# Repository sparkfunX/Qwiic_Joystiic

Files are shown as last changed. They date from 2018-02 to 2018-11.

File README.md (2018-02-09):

# Qwiic_Joystiic
Thumbstick Breakout for the Qwiic System
<br/><br/>
Factory Default I2C Slave Address: 0x20<br/>
<br/>
<h3 style="text-decoration: underline;">I2C Registers</h3><br/>

| Address | Contents |
| --- | --- |
| 0x00-0x01 | Horizontal Position (MSB First) |
| 0x02-0x03 | Vertical Position (MSB First) |
| 0x04 | Button Position |
| 0x06 | Current I2C Slave Address from EEPROM |
<br/>
<h3 style="text-decoration: underline;">I2C Commands</h3><br/>

| Address | Command |
| --- | --- |
| 0x05 | Set I2C Slave Address |

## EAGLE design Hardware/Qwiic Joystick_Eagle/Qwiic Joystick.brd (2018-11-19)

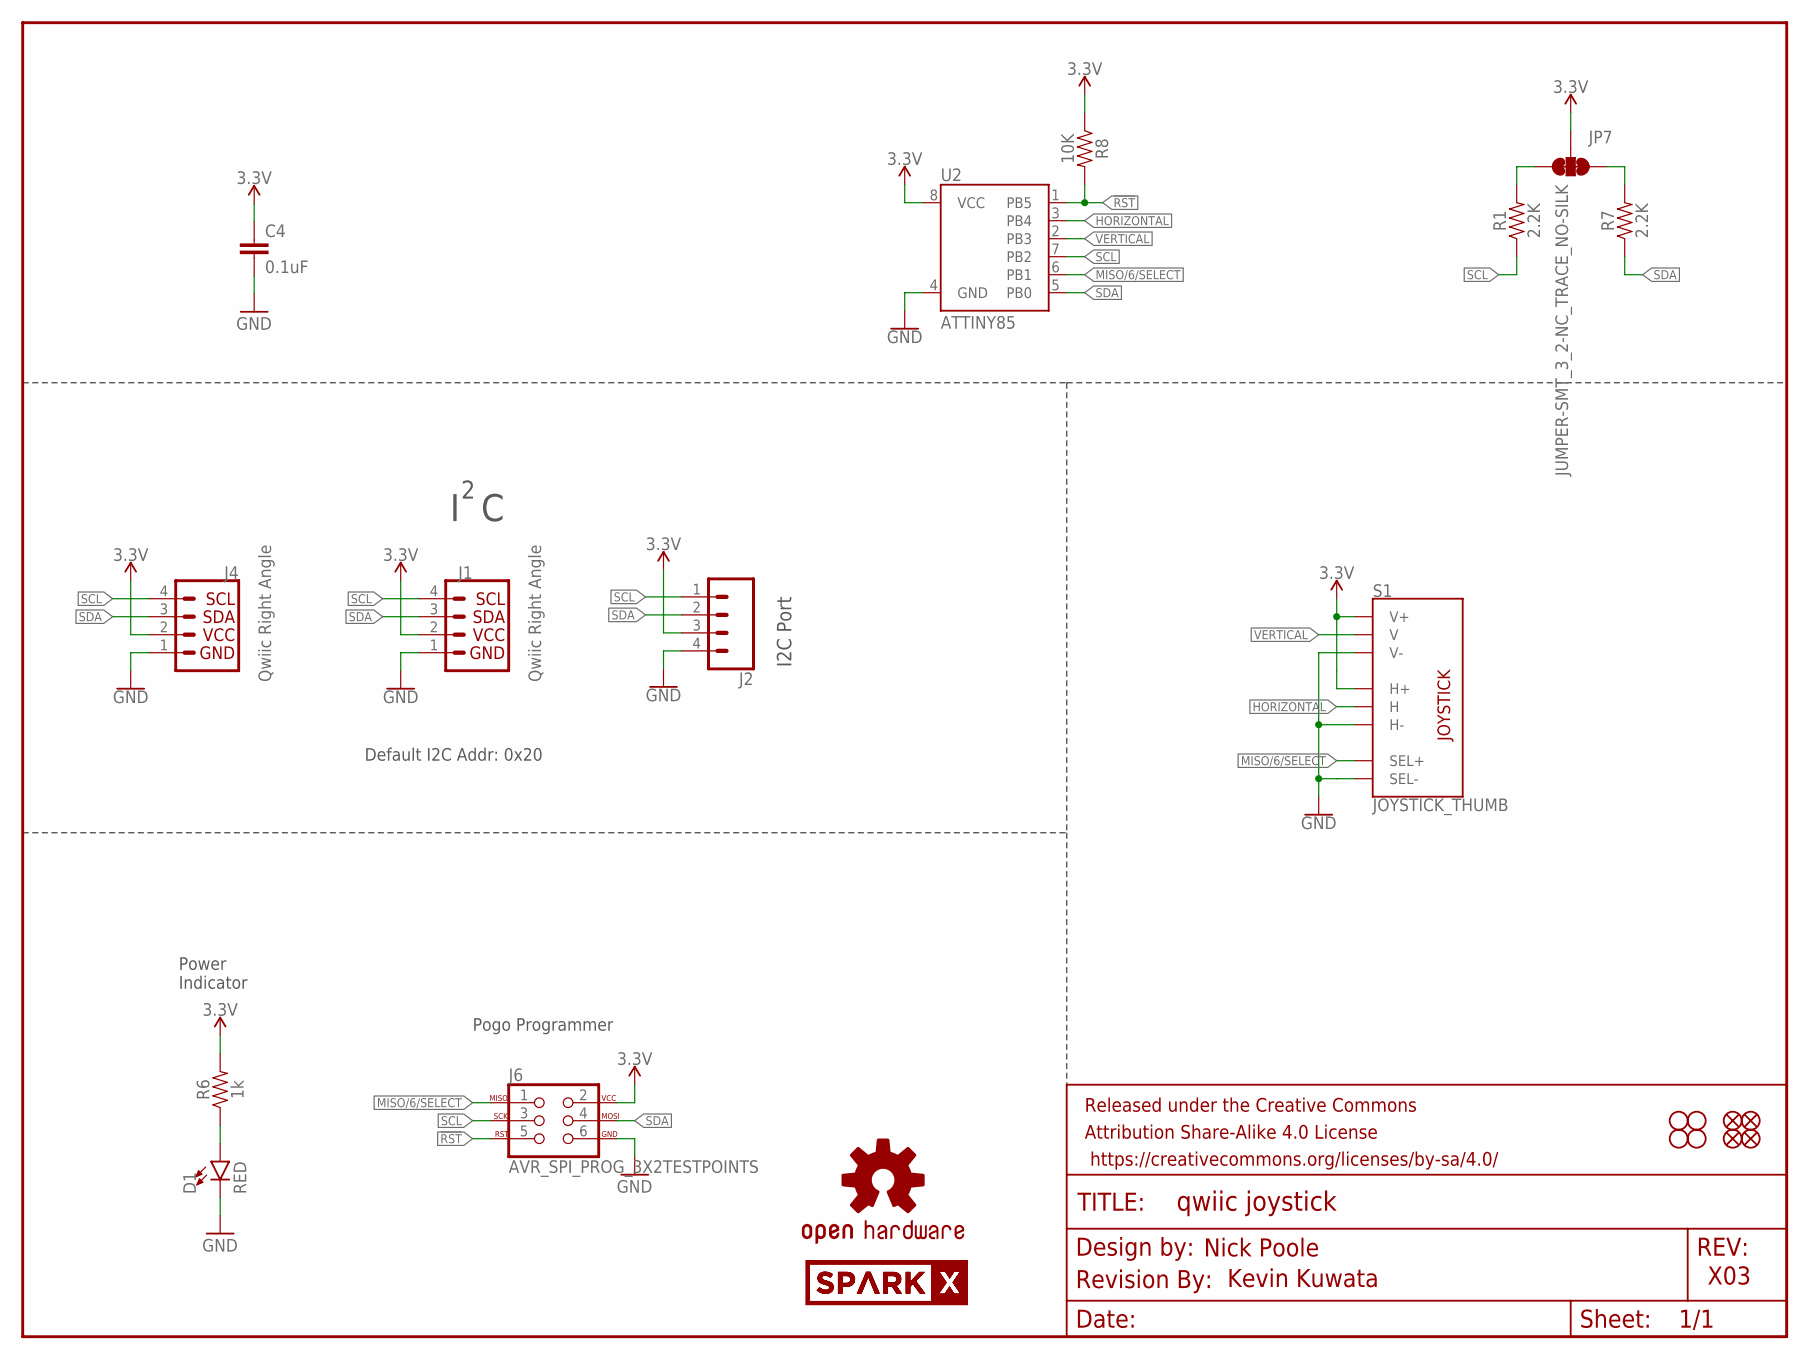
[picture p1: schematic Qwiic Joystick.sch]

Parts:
C4: 0.1uF; 0603
D1: RED; LED-0603
FRAME1: FRAME-LETTER; CREATIVE_COMMONS
H1, H2, H3, H4: STAND-OFF
J1, J4: Qwiic Right Angle; 1X04_1MM_RA
J2: CONN_041X04_NO_SILK; 1X04_NO_SILK
J6: AVR_SPI_PROG_3X2TESTPOINTS; 2X3_TEST_POINTS
JP1, JP2, JP3, JP6: FIDUCIALUFIDUCIAL; MICRO-FIDUCIAL
JP7: JUMPER-SMT_3_2-NC_TRACE_NO-SILK; SMT-JUMPER_3_2-NC_TRACE_NO-SILK
LOGO1: OSHW-LOGOMINI; OSHW-LOGO-MINI
LOGO2: REVISION
R1, R7: 2.2K; 0603
R6: 1k; 0603
R8: 10K; 0603
S1: JOYSTICK_THUMB; JOYSTICK
U2: ATTINY85
U$1, U$2: SPARKX-LOGO3; SPARKX-SMALL

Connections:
3.3V: C4.1, J1.2, J2.3, J4.2, J6.2, JP7.2, R6.2, R8.1, S1.H1 (H+), S1.V1 (V+), U2.8 (VCC)
!RST: J6.5, R8.2, U2.1 (PB5)
GND: C4.2, D1.C, J1.1, J2.4, J4.1, J6.6, S1.B2A (SEL-), S1.H3 (H-), S1.V3 (V-), U2.4 (GND)
HORIZONTAL: S1.H2 (H), U2.3 (PB4)
MISO/6/SELECT: J6.1, S1.B1A (SEL+), U2.6 (PB1)
unnamed: D1.A, R6.1
unnamed: JP7.1, R7.2
unnamed: JP7.3, R1.2
SCL: J1.4, J2.1, J4.4, J6.3, R1.1, U2.7 (PB2)
SDA: J1.3, J2.2, J4.3, J6.4, R7.1, U2.5 (PB0)
VERTICAL: S1.V2 (V), U2.2 (PB3)

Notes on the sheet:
Nick Poole
X03
I C
Power Indicator
Kevin Kuwata
I2C Port
Pogo Programmer
Default I2C Addr: 0x20

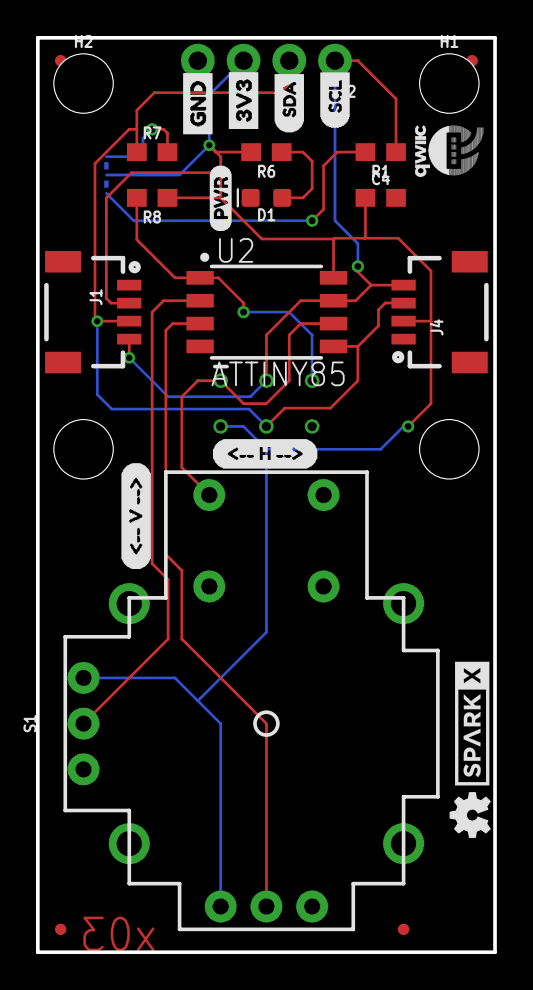
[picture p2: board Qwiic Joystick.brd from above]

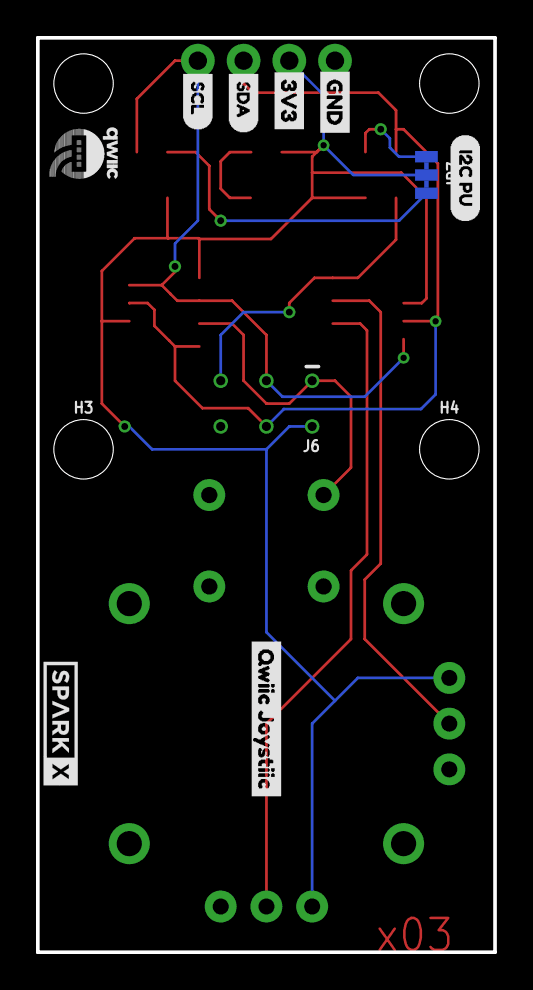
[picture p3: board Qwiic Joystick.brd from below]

Board: 2 copper layers, 25.4 x 50.8 mm, 41 parts (12 on the bottom side), 11 nets.

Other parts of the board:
U$3: QWIIC_JOYSTIIC6
U$4: I2C_PU0
U$5: SDA0
U$6, U$8: GND4
U$7: ###_V_###0
U$9: SCL1
U$10, U$22: QWIIC-LOGO-SMALL
U$11: SCL3
U$12: SDA2
U$14: PWR-()-03
U$15: ###_H_###1
U$16, U$17: 3V35

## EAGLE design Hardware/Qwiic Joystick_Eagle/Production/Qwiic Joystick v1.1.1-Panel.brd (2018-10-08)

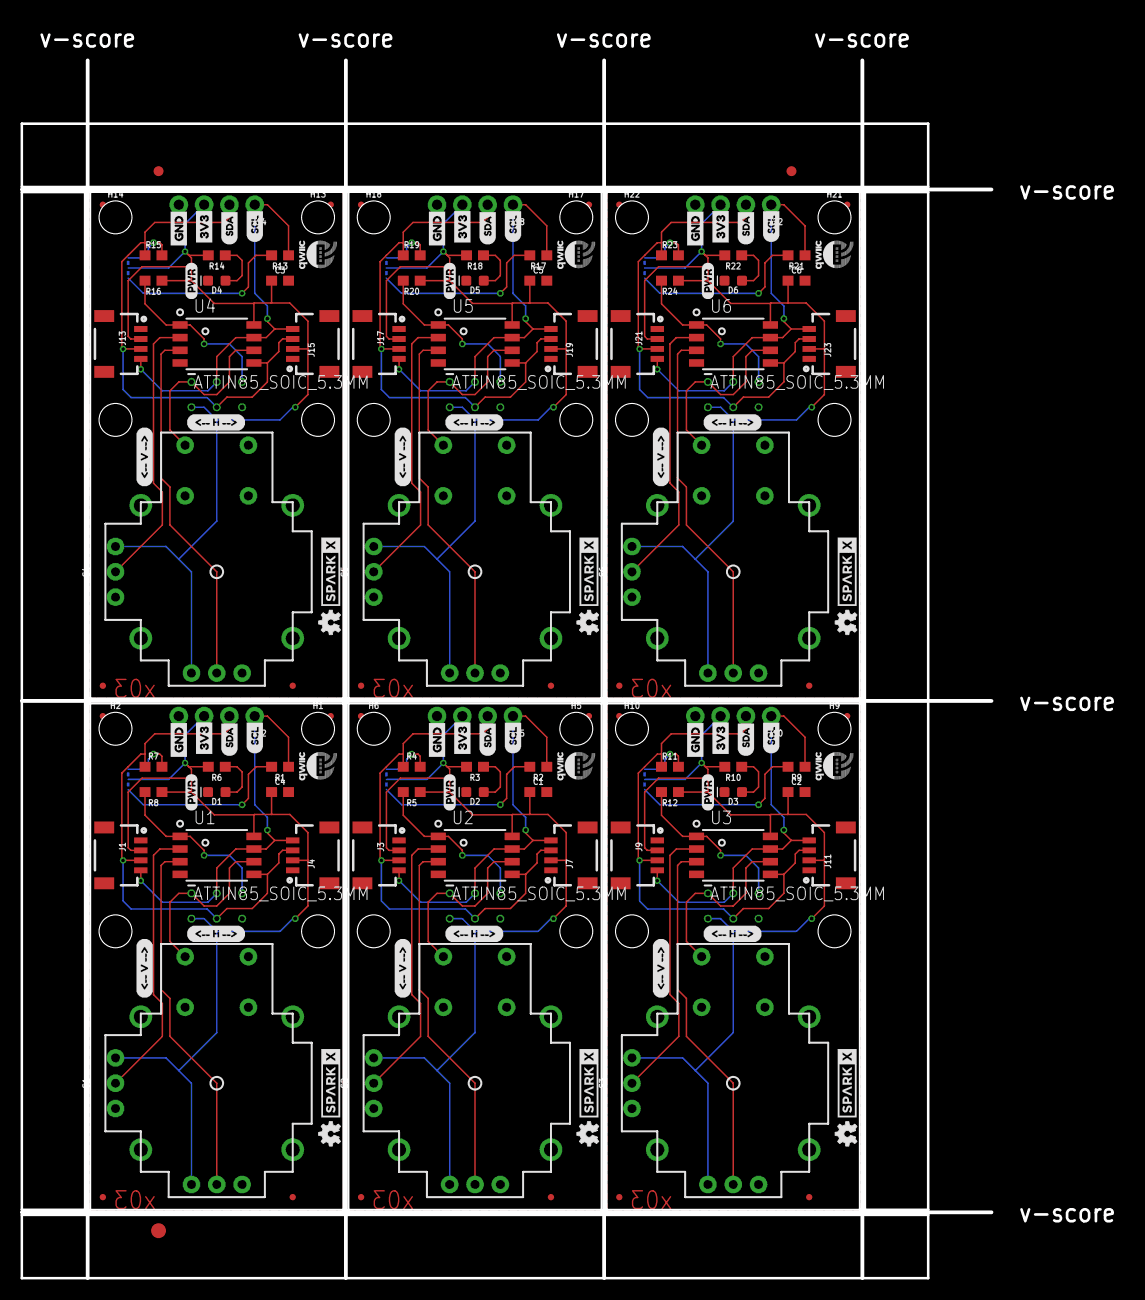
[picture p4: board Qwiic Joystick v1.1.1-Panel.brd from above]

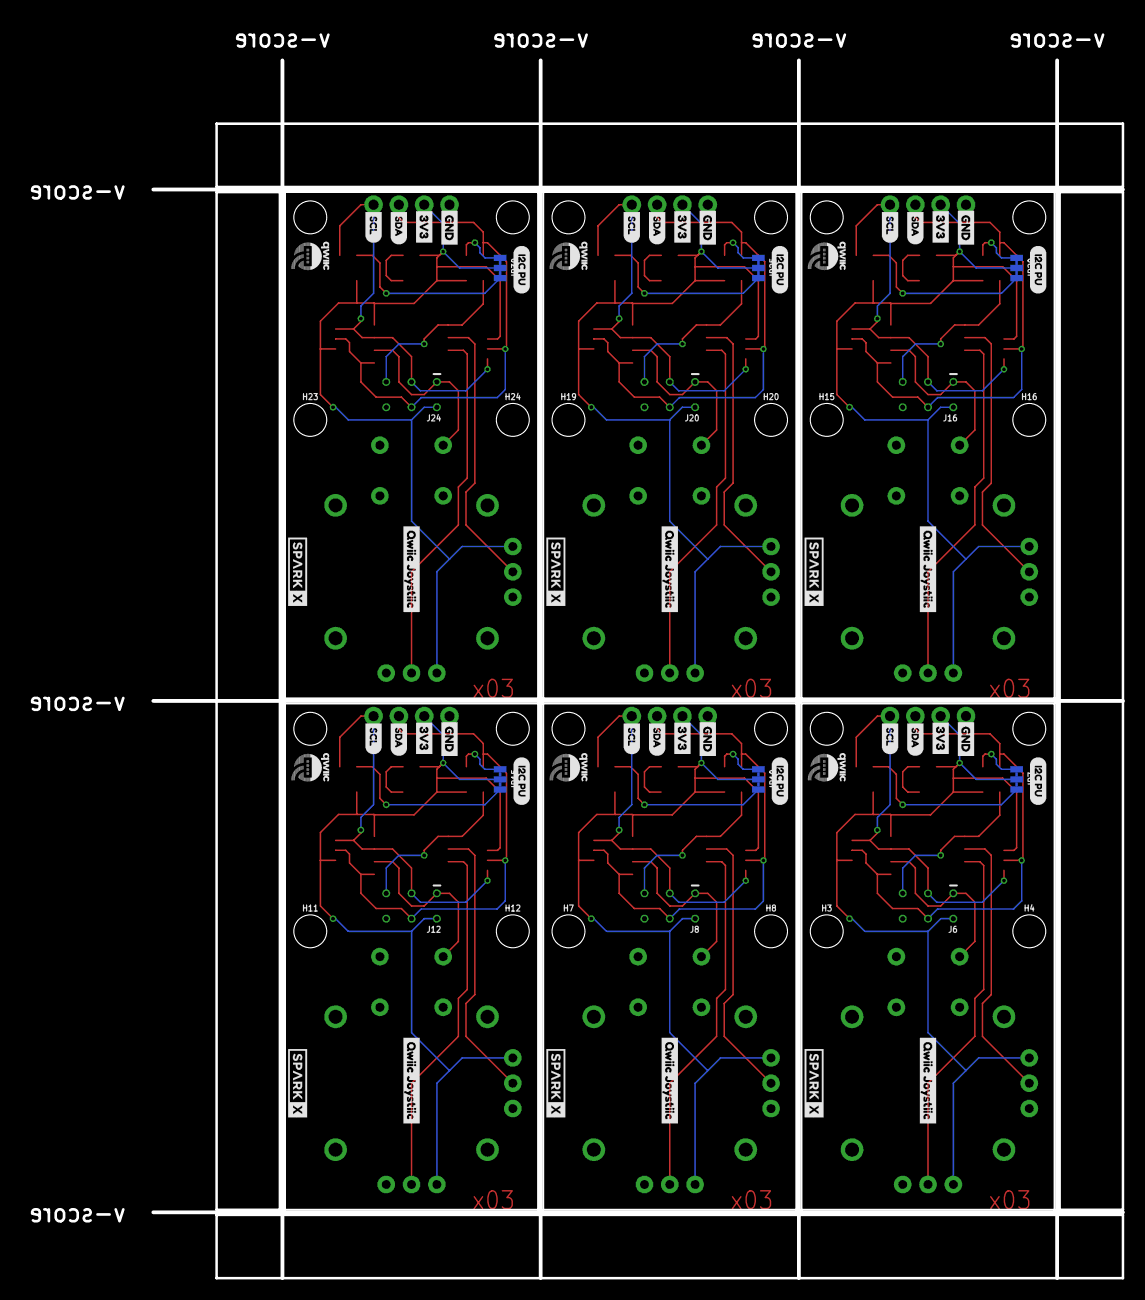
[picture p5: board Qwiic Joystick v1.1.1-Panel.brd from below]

Board: 2 copper layers, 97.3 x 122.2 mm, 243 parts (72 on the bottom side), 66 nets.

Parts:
C1, C2, C3, C4, C5, C6: 0.1uF; 0603
D1, D2, D3, D4, D5, D6: RED; LED-0603
E$1, E$2: FIDUCIAL-1X2
E$3: FIDUCIAL-1.5X3
FRAME1, FRAME2, FRAME3, FRAME4, FRAME5, FRAME6: FRAME-LETTER; CREATIVE_COMMONS
H1, H2, H3, H4, H5, H6, H7, H8, H9, H10, H11, H12, H13, H14, H15, H16, H17, H18, H19, H20, H21, H22, H23, H24: STAND-OFF
J1, J3, J4, J7, J9, J11, J13, J15, J17, J19, J21, J23: Qwiic Right Angle; 1X04_1MM_RA
J2, J5, J10, J14, J18, J22: 1X04_NO_SILK
J6, J8, J12, J16, J20, J24: AVR_SPI_PROG_3X2TESTPOINTS; 2X3_TEST_POINTS
JP1, JP2, JP3, JP4, JP5, JP6, JP8, JP9, JP11, JP12, JP13, JP14, JP16, JP17, JP18, JP19, JP21, JP22, JP23, JP24, JP26, JP27, JP28, JP29: FIDUCIALUFIDUCIAL; MICRO-FIDUCIAL
JP7, JP10, JP15, JP20, JP25, JP30: JUMPER-SMT_3_2-NC_TRACE_NO-SILK; SMT-JUMPER_3_2-NC_TRACE_NO-SILK
LOGO1, LOGO2, LOGO3, LOGO4, LOGO5, LOGO6: OSHW-LOGOMINI; OSHW-LOGO-MINI
R1, R2, R4, R7, R9, R11, R13, R15, R17, R19, R21, R23: 2.2K; 0603
R3, R6, R10, R14, R18, R22: 1k; 0603
R5, R8, R12, R16, R20, R24: 10K; 0603
S1, S2, S3, S4, S5, S6: JOYSTICK_THUMB; JOYSTICK
U1, U2, U3, U4, U5, U6: ATTIN85_SOIC_5.3MM; ATTINY85
U$1, U$2, U$13, U$18, U$35, U$36, U$52, U$53, U$69, U$70, U$86, U$87: SPARKX-LOGO3; SPARKX-SMALL
U$3, U$29, U$46, U$63, U$80, U$97: QWIIC_JOYSTIIC6
U$4, U$34, U$51, U$68, U$85, U$102: I2C_PU0
U$5, U$25, U$42, U$59, U$76, U$93: SDA0
U$6, U$8, U$30, U$31, U$47, U$48, U$64, U$65, U$81, U$82, U$98, U$99: GND4
U$7, U$21, U$39, U$56, U$73, U$90: ###_V_###0
U$9, U$26, U$43, U$60, U$77, U$94: SCL1
U$10, U$19, U$22, U$24, U$37, U$41, U$54, U$58, U$71, U$75, U$88, U$92: QWIIC-LOGO-SMALL
U$11, U$27, U$44, U$61, U$78, U$95: SCL3
U$12, U$28, U$45, U$62, U$79, U$96: SDA2
U$14, U$20, U$38, U$55, U$72, U$89: PWR-()-03
U$15, U$23, U$40, U$57, U$74, U$91: ###_H_###1
U$16, U$17, U$32, U$33, U$49, U$50, U$66, U$67, U$83, U$84, U$100, U$101: 3V35

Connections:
3.3V: C4.1, J1.2, J2.3, J4.2, J6.2, JP7.2, R6.2, R8.1, S1.H1, S1.V1, U1.8
3.3V1: C1.1, J3.2, J5.3, J7.2, J8.2, JP10.2, R3.2, R5.1, S2.H1, S2.V1, U2.8
3.3V2: C2.1, J9.2, J10.3, J11.2, J12.2, JP15.2, R10.2, R12.1, S3.H1, S3.V1, U3.8
3.3V3: C3.1, J13.2, J14.3, J15.2, J16.2, JP20.2, R14.2, R16.1, S4.H1, S4.V1, U4.8
3.3V4: C5.1, J17.2, J18.3, J19.2, J20.2, JP25.2, R18.2, R20.1, S5.H1, S5.V1, U5.8
3.3V5: C6.1, J21.2, J22.3, J23.2, J24.2, JP30.2, R22.2, R24.1, S6.H1, S6.V1, U6.8
!RST: J6.5, R8.2, U1.1
!RST1: J8.5, R5.2, U2.1
!RST2: J12.5, R12.2, U3.1
!RST3: J16.5, R16.2, U4.1
!RST4: J20.5, R20.2, U5.1
!RST5: J24.5, R24.2, U6.1
GND: C4.2, D1.C, J1.1, J2.4, J4.1, J6.6, S1.B2A, S1.H3, S1.V3, U1.4
GND1: C1.2, D2.C, J3.1, J5.4, J7.1, J8.6, S2.B2A, S2.H3, S2.V3, U2.4
GND2: C2.2, D3.C, J9.1, J10.4, J11.1, J12.6, S3.B2A, S3.H3, S3.V3, U3.4
GND3: C3.2, D4.C, J13.1, J14.4, J15.1, J16.6, S4.B2A, S4.H3, S4.V3, U4.4
GND4: C5.2, D5.C, J17.1, J18.4, J19.1, J20.6, S5.B2A, S5.H3, S5.V3, U5.4
GND5: C6.2, D6.C, J21.1, J22.4, J23.1, J24.6, S6.B2A, S6.H3, S6.V3, U6.4
HORIZONTAL: S1.H2, U1.3
HORIZONTAL1: S2.H2, U2.3
HORIZONTAL2: S3.H2, U3.3
HORIZONTAL3: S4.H2, U4.3
HORIZONTAL4: S5.H2, U5.3
HORIZONTAL5: S6.H2, U6.3
MISO/6/SELECT: J6.1, S1.B1A, U1.6
MISO/6/SELECT1: J8.1, S2.B1A, U2.6
MISO/6/SELECT2: J12.1, S3.B1A, U3.6
MISO/6/SELECT3: J16.1, S4.B1A, U4.6
MISO/6/SELECT4: J20.1, S5.B1A, U5.6
MISO/6/SELECT5: J24.1, S6.B1A, U6.6
unnamed: D1.A, R6.1
unnamed: JP7.1, R7.2
unnamed: JP7.3, R1.2
unnamed: D2.A, R3.1
unnamed: JP10.1, R4.2
unnamed: JP10.3, R2.2
unnamed: D3.A, R10.1
unnamed: JP15.1, R11.2
unnamed: JP15.3, R9.2
unnamed: D4.A, R14.1
unnamed: JP20.1, R15.2
unnamed: JP20.3, R13.2
unnamed: D5.A, R18.1
unnamed: JP25.1, R19.2
unnamed: JP25.3, R17.2
unnamed: D6.A, R22.1
unnamed: JP30.1, R23.2
unnamed: JP30.3, R21.2
SCL: J1.4, J2.1, J4.4, J6.3, R1.1, U1.7
SCL1: J3.4, J5.1, J7.4, J8.3, R2.1, U2.7
SCL2: J9.4, J10.1, J11.4, J12.3, R9.1, U3.7
SCL3: J13.4, J14.1, J15.4, J16.3, R13.1, U4.7
SCL4: J17.4, J18.1, J19.4, J20.3, R17.1, U5.7
SCL5: J21.4, J22.1, J23.4, J24.3, R21.1, U6.7
SDA: J1.3, J2.2, J4.3, J6.4, R7.1, U1.5
SDA1: J3.3, J5.2, J7.3, J8.4, R4.1, U2.5
SDA2: J9.3, J10.2, J11.3, J12.4, R11.1, U3.5
SDA3: J13.3, J14.2, J15.3, J16.4, R15.1, U4.5
SDA4: J17.3, J18.2, J19.3, J20.4, R19.1, U5.5
SDA5: J21.3, J22.2, J23.3, J24.4, R23.1, U6.5
VERTICAL: S1.V2, U1.2
VERTICAL1: S2.V2, U2.2
VERTICAL2: S3.V2, U3.2
VERTICAL3: S4.V2, U4.2
VERTICAL4: S5.V2, U5.2
VERTICAL5: S6.V2, U6.2

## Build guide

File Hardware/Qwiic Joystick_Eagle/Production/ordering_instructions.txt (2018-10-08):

panel size, 91x116mm
PCB thickness, 1.6mm
number of layers, 2
soldermask color, Black
silkscreen color, White
oz copper, 1oz
finish, HASL lead free
stencils, top
pcs per panel, 6

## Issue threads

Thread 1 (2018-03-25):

No Wire.endTransmission() after a Wire.requestFrom() please.

Koepel, 2018-03-25:
In the file "Example3-ReactionGame.ino" there is twice a Wire.endTransmission() after a Wire.requestFrom().
Explanation: [Common-mistakes#2](https://github.com/Koepel/How-to-use-the-Arduino-Wire-library/wiki/Common-mistakes#2)

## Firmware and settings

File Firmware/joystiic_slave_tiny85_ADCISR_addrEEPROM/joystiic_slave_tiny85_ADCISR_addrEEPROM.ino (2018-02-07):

#include <TinyWire.h> //https://github.com/lucullusTheOnly/TinyWire
#include <avr/sleep.h>
#include <EEPROM.h>

#define REG_MAP_SIZE         7
#define MAX_SENT_BYTES       3

#define ADC1_ADDRESS_MSB         0x00
#define ADC2_ADDRESS_MSB         0x02
#define BTN1_ADDRESS             0x04

byte registerMap[REG_MAP_SIZE];
byte registerMapTemp[REG_MAP_SIZE - 1];
byte receivedCommands[MAX_SENT_BYTES];

//"factory default" slave address
byte slave_addr = 0x20;

int adc1 = 0;
int adc2 = 0;
byte btn = 0b00000000;

void setup()
{

  //Check EEPROM for a slave address
  //If no address is stored, set to "factory default"

  byte eepromVal;
  EEPROM.get(0, eepromVal);

  if (eepromVal == 0xFF) {
    EEPROM.put(0, 0x20);
  } else {
    //If there is an address in EEPROM, set it
    slave_addr = eepromVal;
  }

  //Setup TinyWire
  TinyWire.begin(slave_addr);
  TinyWire.onRequest(requestEvent);
  TinyWire.onReceive(receiveEvent);

  //Set pullup on pin 1
  pinMode(1, INPUT);
  digitalWrite(1, 1);

  //Shut off ADC
  ADCSRA &= ~(1 << ADEN);

}



void loop() {

  //Sleep until interrupt
  set_sleep_mode(SLEEP_MODE_IDLE);
  sleep_mode();

}

void requestEvent()
{

  //Bring up ADC
  ADCSRA |= (1 << ADEN);

  //Read all the things
  adc1 = analogRead(A2);
  adc2 = analogRead(A3);
  if (digitalRead(1) == 0) {
    btn = 0b00000000;
  } else {
    btn = 0b00000001;
  }

  //Shut off ADC
  ADCSRA &= ~(1 << ADEN);

  //Jam our stuff into an array
  byte * bytePointer;
  byte arrayIndex = 0;

  bytePointer = (byte*)&adc1;
  for (int i = 1; i > -1; i--)
  {
    registerMap[arrayIndex] = bytePointer[i];  //increment pointer to store each byte
    arrayIndex++;
  }

  bytePointer = (byte*)&adc2;
  for (int i = 1; i > -1; i--)
  {
    registerMap[arrayIndex] = bytePointer[i];  //increment pointer to store each byte
    arrayIndex++;
  }

  registerMap[4] = btn;

  switch (receivedCommands[0]) {

    case 0x00:

      TinyWire.send(registerMap[0]);
      TinyWire.send(registerMap[1]);
      break;

    case 0x02:

      TinyWire.send(registerMap[2]);
      TinyWire.send(registerMap[3]);
      break;

    case 0x04:

      TinyWire.send(registerMap[4]);
      break;

    case 0x06:

      byte eepromVal;
      EEPROM.get(0, eepromVal);
      TinyWire.send(eepromVal);
      break;

    default:
      break;

  }

}

void receiveEvent(int bytesReceived)
{

  for (int a = 0; a < bytesReceived; a++)
  {
    if ( a < MAX_SENT_BYTES)
    {
      receivedCommands[a] = TinyWire.read(); //grab stuff and jam it into the command buffer
    }
    else
    {
      TinyWire.read(); //if we receive more data than allowed, chuck it
    }
  }

  if (bytesReceived == 1 && (receivedCommands[0] < REG_MAP_SIZE)) //if we got a byte within the register map range, keep it
  {

    return;
  }

  if (bytesReceived == 1 && (receivedCommands[0] >= REG_MAP_SIZE)) //if we got a byte outside the register map range, chuck it
  {
    receivedCommands[0] = 0x00;
    return;
  }

  if (bytesReceived > 1 && (receivedCommands[0] == 0x05)) {

    if (receivedCommands[1] < 0x80 && receivedCommands[1] > 0x00) {
      EEPROM.put(0, receivedCommands[1]);
    }
    receivedCommands[0] = 0x00;
    receivedCommands[1] = 0x00;
    return;
  }

  return; // ignore anything else and return

}

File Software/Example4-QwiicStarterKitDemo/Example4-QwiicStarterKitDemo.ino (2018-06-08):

/******************************************************************************
Qwiic Starter Kit Game 
Owen Lyke @ SparkX
June 8th 2018

This sketch shows how Qwuiicly you can make a snake-like game (minus death!) 
All parts (BlackboardMini OLED Display, Acceleromenter, and Joystiic) are 
included in the Qwiic Starter Kit (available: https://www.sparkfun.com/products/14752)

Wiring:
The hardware setup is incredibly simple thanks to the magic of I2C! All you 
have to do is connect all the parts to one another with the Qwiic cables and
make sure that they are connected to the BlackBoard. The order in which the
parts are all strung together doesn't matter!

Playing the Game:
Make sure the libraries for the OLED and the Accelerometer (MMA8452Q) are
installed, then compile and upload the code to the BlackBoard. 
With the acclerometer flat use the Joystiic to move the ball toward the targets. 
For an additional challenge tilt the accelerometer - this will cause 'gravity' 
to affect the ball. 
You can even use the accelerometer as your controller!

Going Further:
Now you know how to use the Qwiic system and you have some sensors to play with.
Try using the VCNL4040 proximity sensor to reset the score when you wave your hand.
Try changing the code so that the ball bounces off walls!
The sky's the limit when it comes to making your ideas into reality. Check out
the host of other Qwiic parts like pressure sensors, MP3 players, thermal imagers, 
and lots more!
******************************************************************************/

#include <Wire.h>               // Qwiic parts use the I2C communication protocol, handled by Wire
#include <SFE_MicroOLED.h>      // Include the SFE_MicroOLED library                                    http://librarymanager/All#Sparkfun_Micro_OLED_Breakout
#include <SparkFun_MMA8452Q.h>  // Includes the SFE_MMA8452Q library                                    http://librarymanager/All#Sparkfun_MMA8452Q


//////////////////////////
// MicroOLED Definition //
//////////////////////////
#define PIN_RESET 9                     // The library assumes a reset pin is necessary. The Qwiic OLED has RST hard-wired, so pick an arbitrarty IO pin that is not being used
#define DC_JUMPER 1                     // Out-of-the-box the OLED's address jumper is open so use (1). If the jumper is closed then use 0 here
MicroOLED oled(PIN_RESET, DC_JUMPER);   // Make an object of the MicroOLED class called "oled"

//////////////////////////////
// Accelerometer Definition //
//////////////////////////////
MMA8452Q accel;                         // Make an object of the MMA8452Q class called "accel"
byte pl;                                // This means "portrait v landscape" but it can actuall hold 5 different values which are determined by the accelerometer

/////////////////////////
// Joystiic Definition //
/////////////////////////
byte JOY_ADDR = 0x20;                   // Not using a library for the Joystiic, so we need to know the I2C address
int reading = 0;                        // This variable will be used to hold the value that the Joystiic returns

/////////////////////////////
// Game Variables (Global) //
/////////////////////////////
unsigned int score = 0;

// User input from Joystiic
byte prevB = 1;   // Previous button value, used to determine "edges" of button presses
byte B = 1;       // Button value now
int H = 0;        // Horizontal ADC counts
int V = 0;        // Vertical ADC counts

// Display options
boolean invertOLED  = false;  
byte r = 4;                     // Ball radius
byte tR = 5;                    // Target radius

// Physics
int pX = 32;    // X position of the ball
int pY = 32;    // Y position of the ball
int vX = 0;     // X velocity of the ball
int vY = 0;     // Y velocity of the ball
int aX = 0;     // X acceleration of the ball
int aY = 0;     // Y acceleration of the ball

// 
int tX = 0;     // Holds the X location of the target
int tY = 0;     // Holds the Y location of the target


void setup() {
  delay(100);       // Delay allows OLED power supply to stabilize
  oled.begin();     // Initialize the OLED
  oled.clear(ALL);  // Clear the display's internal memory
  oled.display();   // Display what's in the buffer (splashscreen)
  delay(1000);      // Delay 1000 ms

  accel.init();     // Start up the accelerometer
  
  randomSeed(analogRead(A0) + analogRead(A1));    // Provide a seed for the random generator
  generateTarget();                               // Use randm functions to set the initial target location
}

void loop() {
  checkJoystiic();          // This function talks to the Joystiic to get the latest values
  checkAccelerometer();     // A similar process for the accelerometer
  updateBall();             // Now with the new controls known we can run the physics of the game to move the ball
  checkTarget();            // And with the ball in a new position we can check to see if it is on the target yet
  printScore();             // Good to know how well you're doing!
  
  oled.display();           // Some above functions modified the data in the OLED's memory, so now tell the display to show that new info    
                            // Don't use a delay in this loop because it already takes long enough for the OLED to refresh
}


void generateTarget( void )
{
  tX = random(2, 61);
  tY = random(2,45);
}

void checkTarget( void )
{
  if(((pX - tX) > -5) && ((pX - tX) < 5))     // Ball is within 5 pixels of target in X
  {
    if(((pY - tY) > -5) && ((pY - tY) < 5))   // Ball within 5 pixels of target in Y
    {
      generateTarget();                       // Create new target
      score++;                                // Good job!
    }
  }
  oled.circle(tX, tY, tR);                    // Draw circle at new target
}

void printScore( void )
{
  char c = '0';
  switch(score)
  {
    case 0 : c = '0'; break;
    case 1 : c = '1'; break;
    case 2 : c = '2'; break;
    case 3 : c = '3'; break;
    case 4 : c = '4'; break;
    case 5 : c = '5'; break;
    case 6 : c = '6'; break;
    case 7 : c = '7'; break;
    case 8 : c = '8'; break;
    case 9 : c = '9'; break;
    default : score = 0; break;
  }
  oled.drawChar(56,2,c);
}
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

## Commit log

2018-02-21 v1.1
    - Buzzard Silkscreen
    - Wide SOIC footprint
    - Power LED
    [Joystiic-B.Cu.gbl, Joystiic-B.Mask.gbs, Joystiic-B.SilkS.gbo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]
2018-06-08 Added a Qwiic starter kit demo
    Uses the Joystiic, MicroOLED, and MMA8452Q accelerometer to make a snake-like game
2018-10-08 Eagle version of Joystiic
    Including the Eagle project for the Joystiic.
    [Qwiic Joystick v1.1.1-Panel.GBL, Qwiic Joystick v1.1.1-Panel.GBO, Qwiic Joystick v1.1.1-Panel.GBS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]
2018-11-19 Cleaned repo
    Cleaned up the repo, made parts sparkle parts.
    [Joystiic-B.Cu.gbl, Joystiic-B.Mask.gbs, Joystiic-B.SilkS.gbo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]

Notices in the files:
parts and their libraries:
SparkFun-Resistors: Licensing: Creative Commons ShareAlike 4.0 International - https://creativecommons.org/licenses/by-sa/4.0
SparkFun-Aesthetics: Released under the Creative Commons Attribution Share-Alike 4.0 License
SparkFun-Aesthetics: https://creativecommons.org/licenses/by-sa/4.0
